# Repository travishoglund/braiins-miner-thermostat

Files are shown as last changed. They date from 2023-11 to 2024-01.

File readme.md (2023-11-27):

# Braiins Miner Thermostat

The purpose of this repo is to help you setup your own Braiins Thermostat for your Miner (S9, S17, S19 supported).

# Features
`Open Source`: Easy to build and assemble if you are a DIY person :)

`Thermostat`: Maintains temperature of your area by enabling or disabling the miner based on the deadband range you set for room temperature.

`Vented`: 3D model is vented so you don't need to run a fan on the unit

## Required Parts:

Approximate Cost: $90

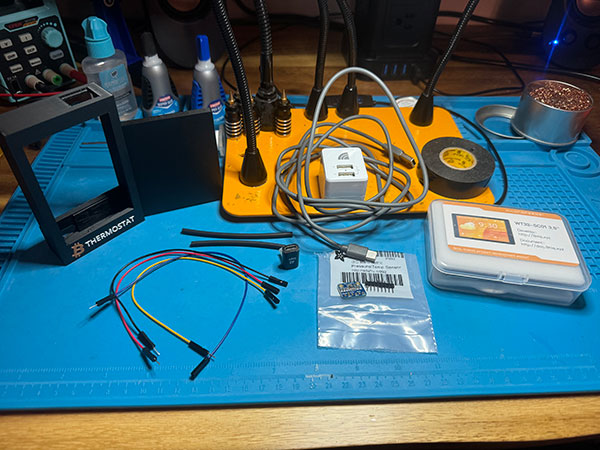
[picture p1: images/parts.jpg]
Parts


- [ESP32 Micro Controller](https://amzn.to/46Gki7e)
- [Temperature Sensor](https://amzn.to/46x0Yt0)
- [90 Degree USBC Adapter](https://amzn.to/3sXdmEE)
- [Shrink Tubing](https://amzn.to/3ojl0H0)
- [Jumper Wires](https://amzn.to/3GPbUIl)
- [90 Degree Jumper Adapter](https://www.amazon.com/dp/B07C89T16T/ref=cm_sw_r_as_gl_api_gl_i_YCH53DA426VD8DCADNQT?linkCode=ml2&tag=wpwtg-20)
- [USBC Power Cable](https://amzn.to/3N3CCjo)
- [Power Adapter](https://amzn.to/49RG3DN)
- You will also need a 3D printer, soldering iron, and an Exacto Knife to clean up the 3D model.

## Assembly Instructions

### Print the 3D Model
Print the models and remove the supports.  The case and door STL's are located in the 3D folder in the repo.<br /><br />
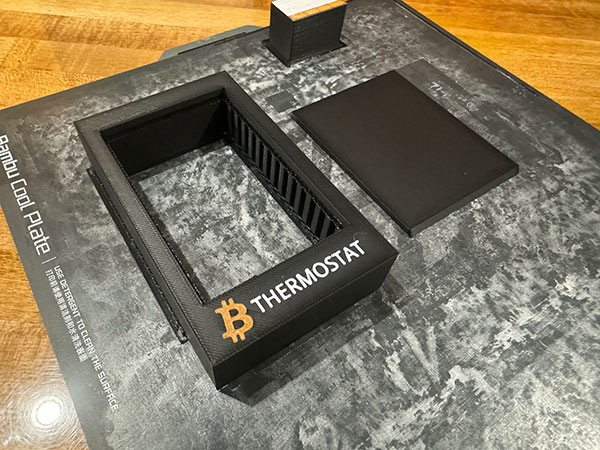
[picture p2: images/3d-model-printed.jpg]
3D Model


### Micro Controller Configuration
While that is printing, lets prepare the micro controller.
- Download the [Arduino IDE](https://www.arduino.cc/en/software)
- Once installed, connect the micro controller to your computer via USBC, and from the dropdown select "Select other board and port...", and select the "ESP32 Dev Module" and on the right select your USB port that it is connected to.
- Copy and paste the code from the arduino-code folder into the editor. Change the variable `thermostatTargetTemp` to your desired room temperature.  (In a future commit this will not be necessary).
- Click the upload button (the second button on the top left).  Once it uploads to the micro controller you should see the Bitcoin ATM screen.  It can safely be removed from the computer and is ready for the assembly into our box.

### Prepare the temperature sensor

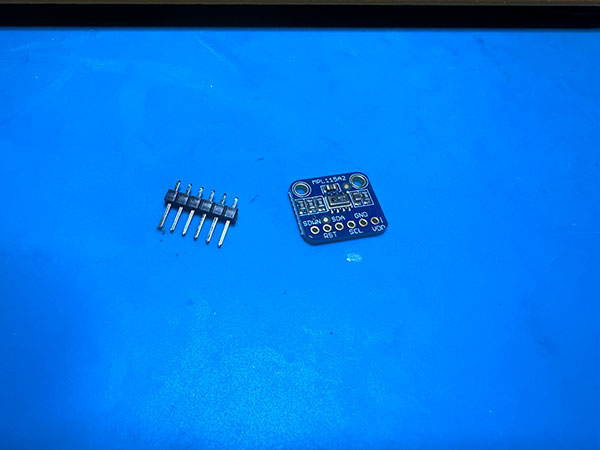
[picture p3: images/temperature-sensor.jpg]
Temperature Sensor
<br />

Solder the pins with the small side up through the board.  I recommend using some flux as the soldering flows much smoother with a small dab of it.  It should look like this:<br /><br />
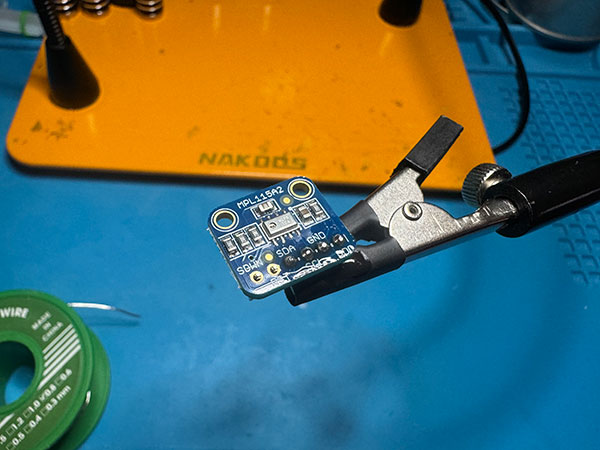
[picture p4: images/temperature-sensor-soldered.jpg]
Temperature Sensor Soldered


### Prepare the jumper wires

Next, we are going to modify the male end of our jumper wires to have a 90 degree bend.<br /><br />
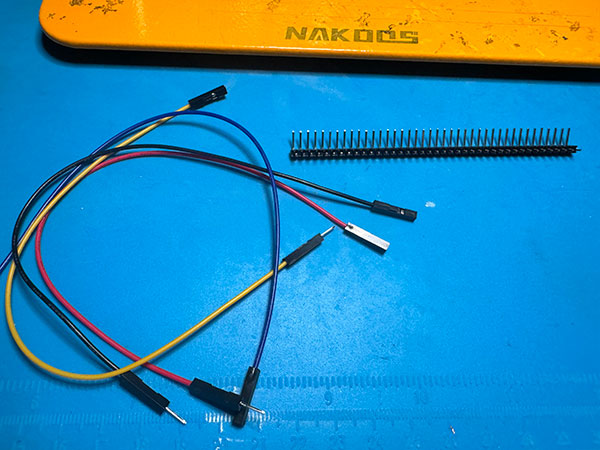
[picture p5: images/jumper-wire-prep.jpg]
Jumper wires


Break apart our 90 degree adapters to individual pieces (qty 4), and solder them to the ends of our jumper wires.<br /><br />
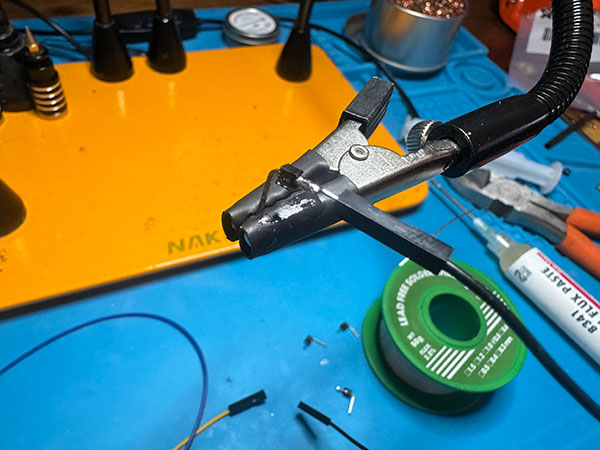
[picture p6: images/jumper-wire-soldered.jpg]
Jumper wires soldered


When soldering is done, cut some shrink tubing (1/8") to about an inch long and heat them around our conversion.<br /><br />
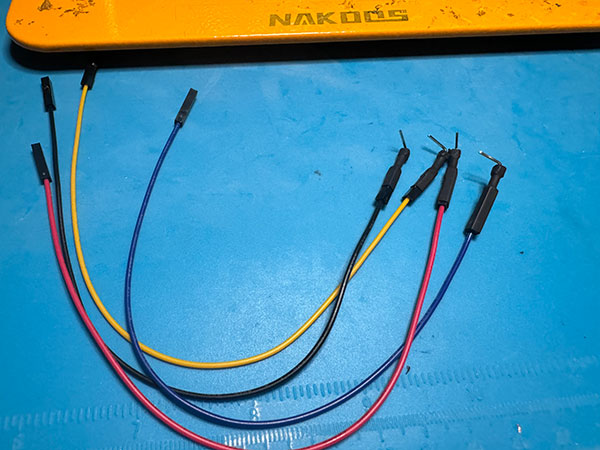
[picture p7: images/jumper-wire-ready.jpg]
Jumper wires complete


### Fitting everything together

Now that everything is ready, we get to assemble everything together.  You will need your 3D model, USBC 90 degree adapter, and Micro Controller display.<br /><br />
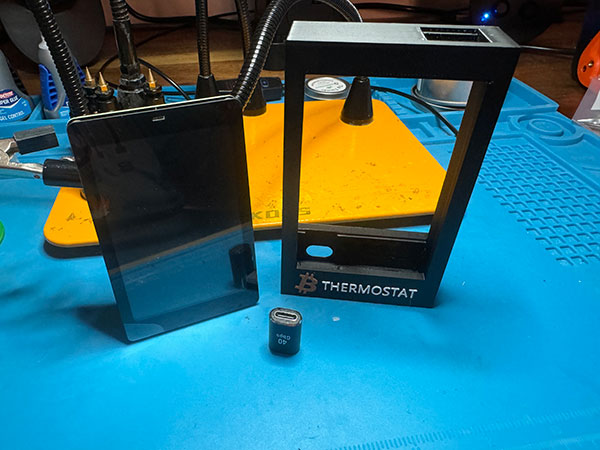
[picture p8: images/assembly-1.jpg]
Assembly 1


Slide the adapter in from the top until you can slide it through the hole in the back of the model.<br /><br />
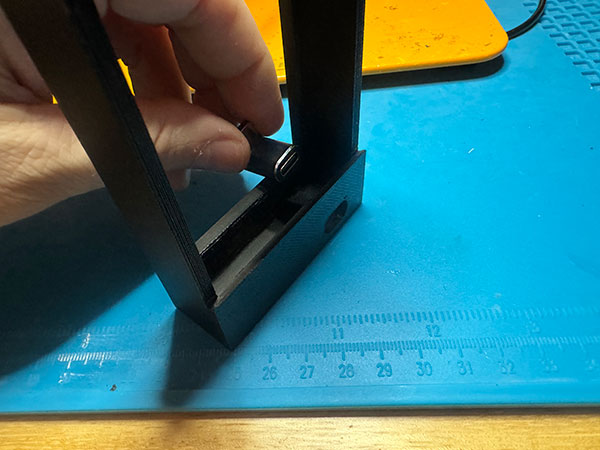
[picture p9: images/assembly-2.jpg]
Assembly 2
<br />
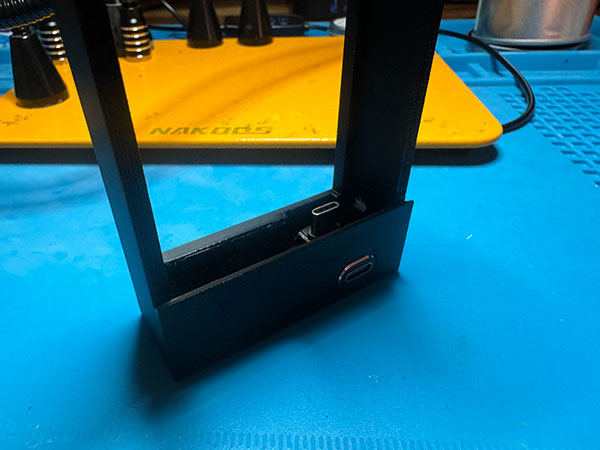
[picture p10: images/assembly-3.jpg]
Assembly 3


Next, take apart the LCD panel. There are tiny little tabs that lock into the metal plate so gently pry them until you can get the top and bottom separated.<br /> <br />
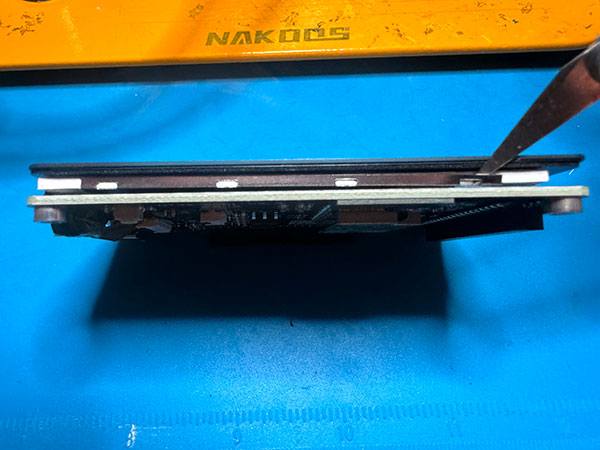
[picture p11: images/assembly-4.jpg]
Assembly 4
<br />
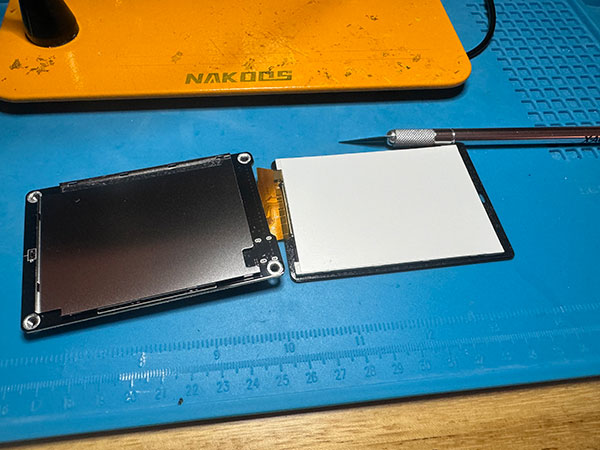
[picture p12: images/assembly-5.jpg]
Assembly 5
<br />

Next, bring the display through the unit at an angle, straighten it out, and line up the usbc port to snap it down into place.<br /><br />
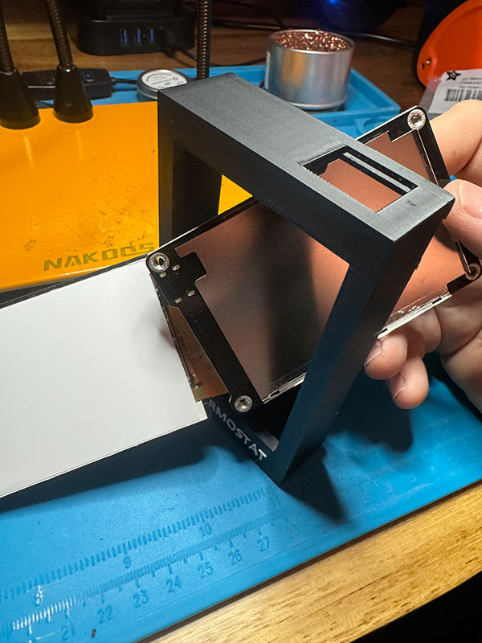
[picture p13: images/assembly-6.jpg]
Assembly 6
<br />
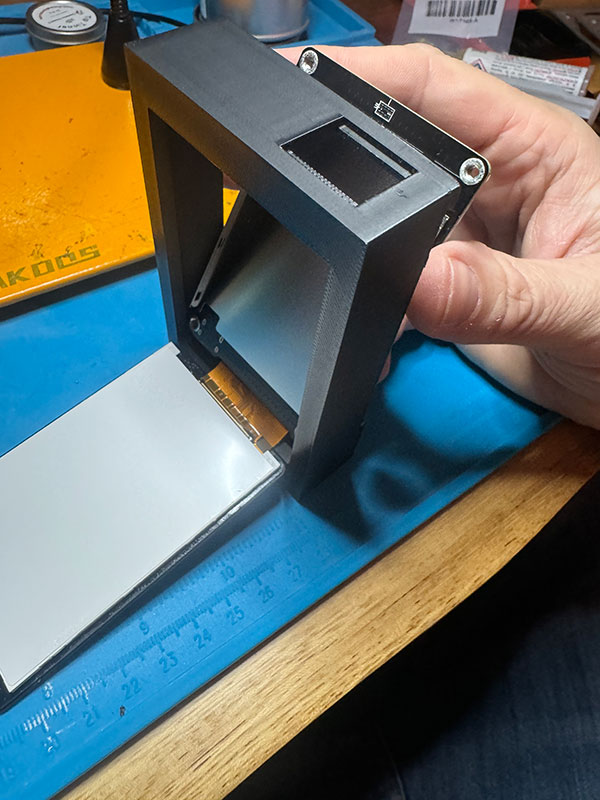
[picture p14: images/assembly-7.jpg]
Assembly 7
<br />
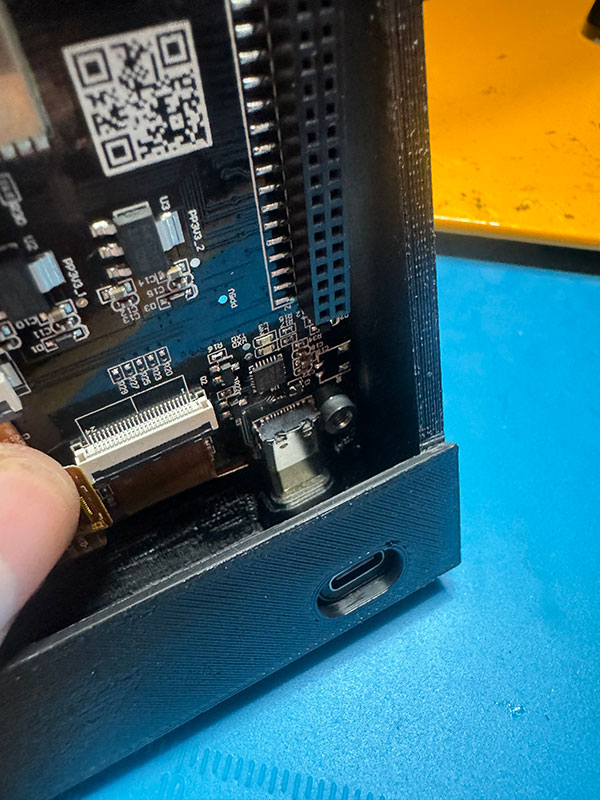
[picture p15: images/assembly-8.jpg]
Assembly 8
<br />

Everything should lock together when you press the display against itself.  I do recommend putting a small amount of hot glue in the top lef/right corners and on the UBBC port inside the model to hold everything even tighter ito place. <br /><br />
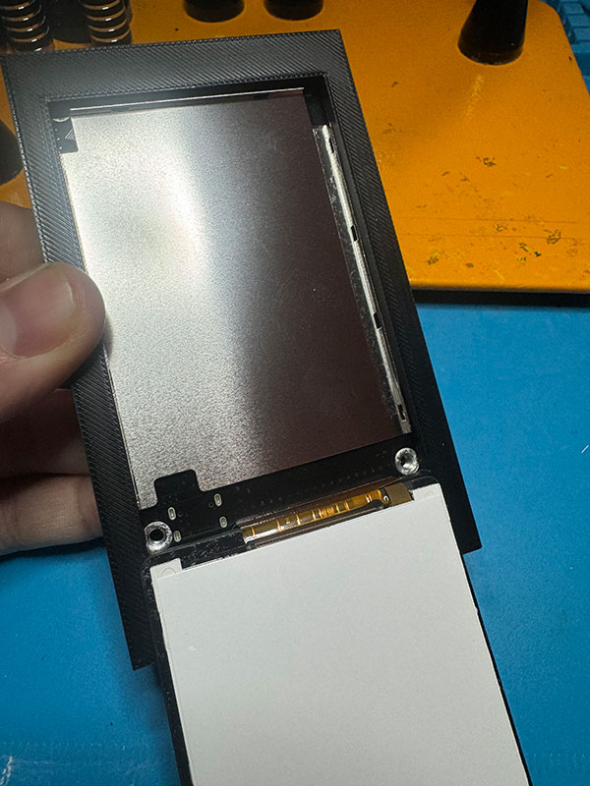
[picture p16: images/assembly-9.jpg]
Assembly 9
<br />
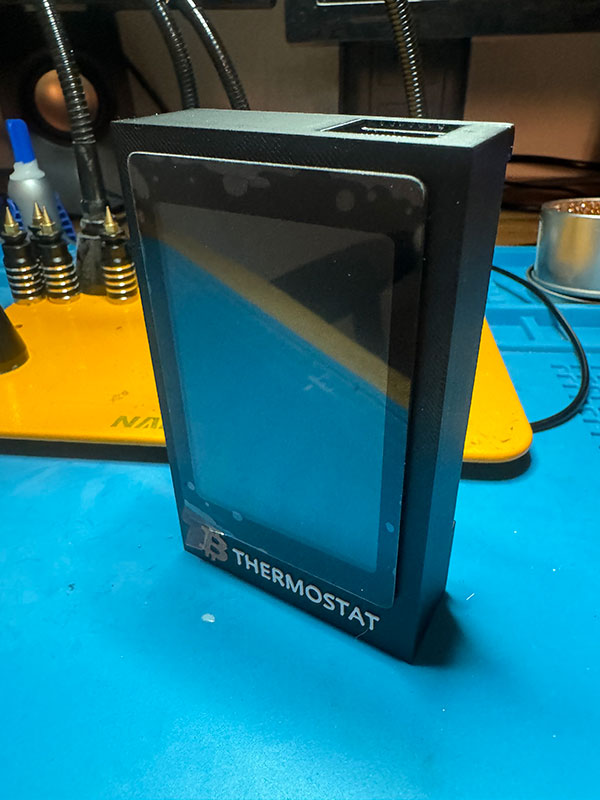
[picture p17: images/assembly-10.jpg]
Assembly 10
<br />

Push the thermostat sensor into the top of the model as shown below<br /><br />
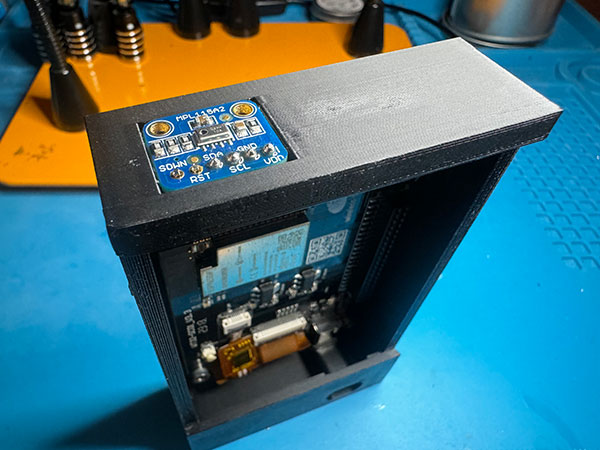
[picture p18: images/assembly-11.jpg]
Assembly 11
<br />

Connect the wires to thermostat sensor and microcontroller as shown:<br /><br />
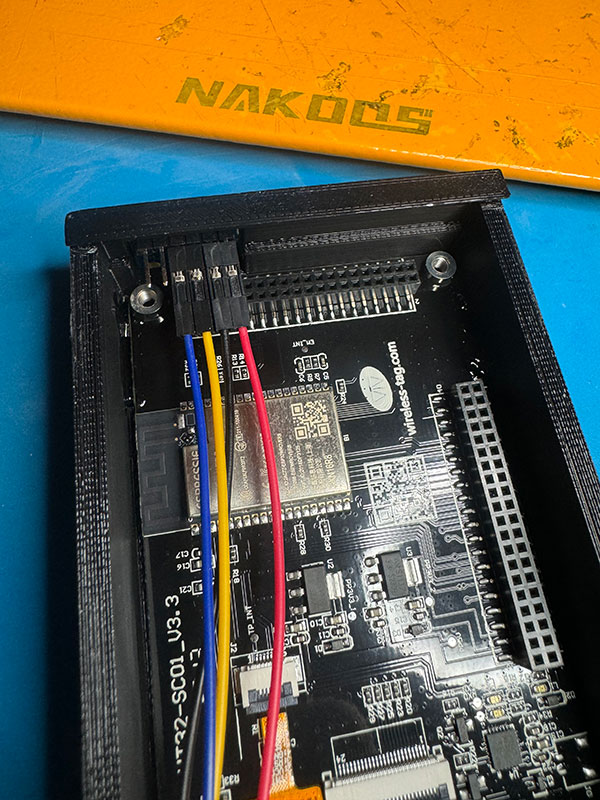
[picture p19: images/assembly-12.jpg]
Assembly 12
<br />

The micro controller pins all go along the back row and are as follows (from the right):
- Red (1)
- Black (3)
- Yellow (8)
- Blue (9)

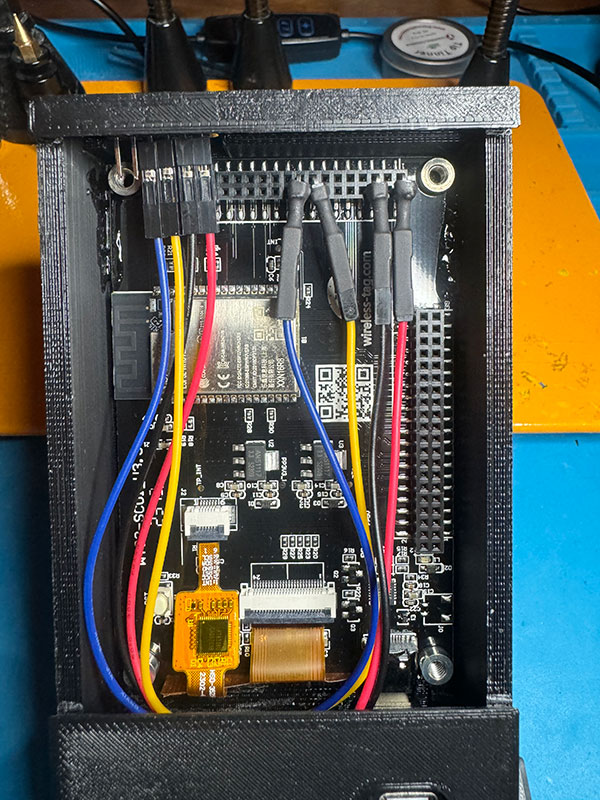
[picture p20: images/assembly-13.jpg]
Assembly 13
<br />

Slide the door on the back and our assembly is ready to run!<br />
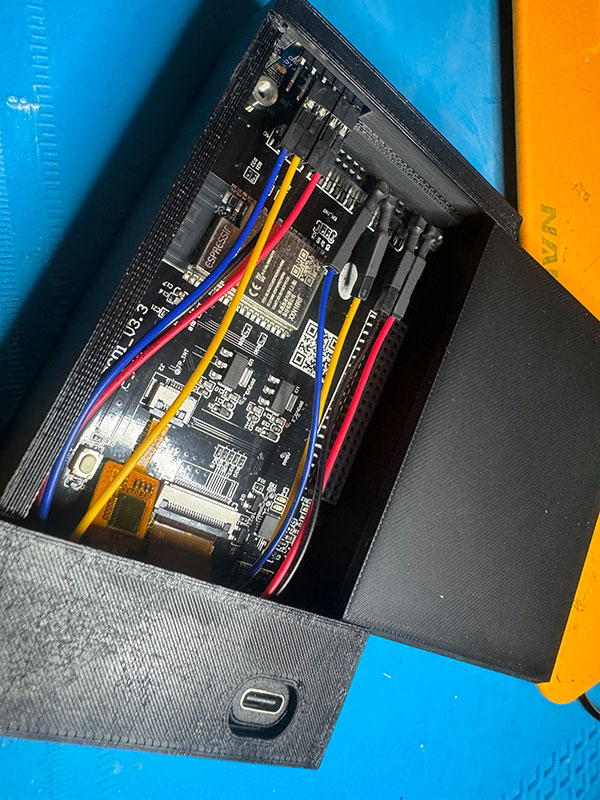
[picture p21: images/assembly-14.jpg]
Assembly 14
<br />
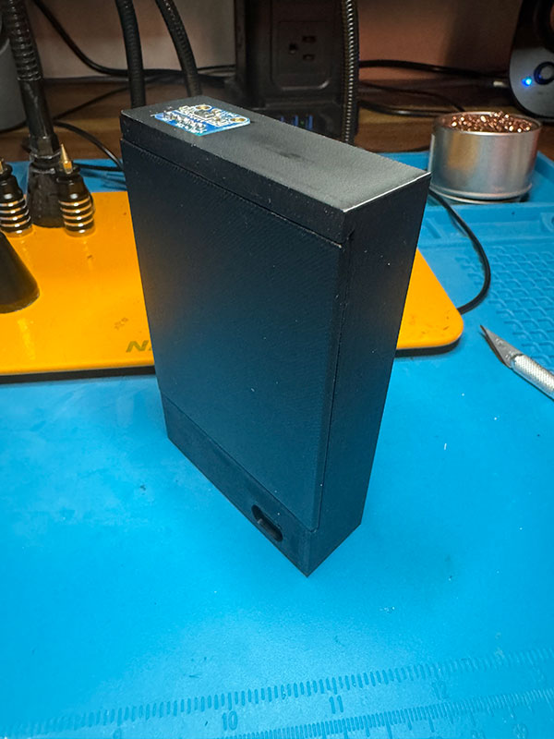
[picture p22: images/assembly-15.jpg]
Assembly 15
<br />
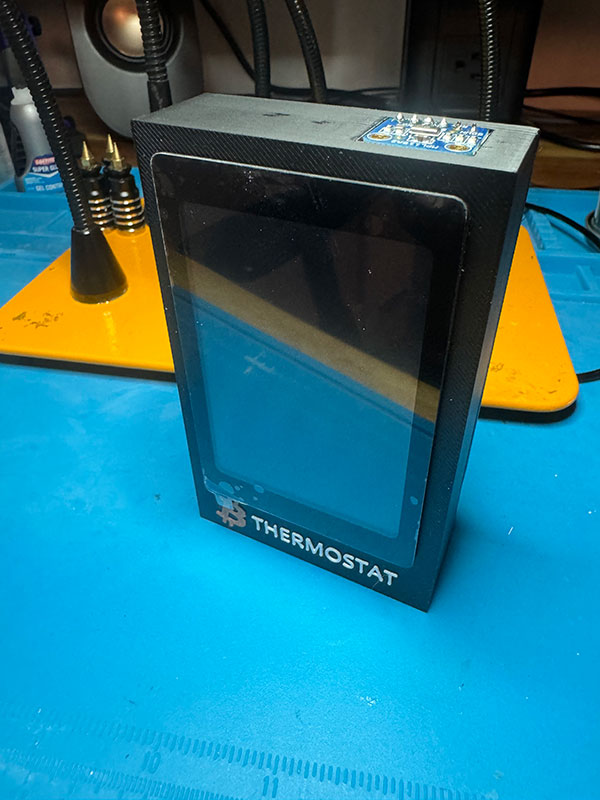
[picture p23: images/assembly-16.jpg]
Assembly 16
<br />

### Final Product
Our final product is ready to use :) <br /><br />

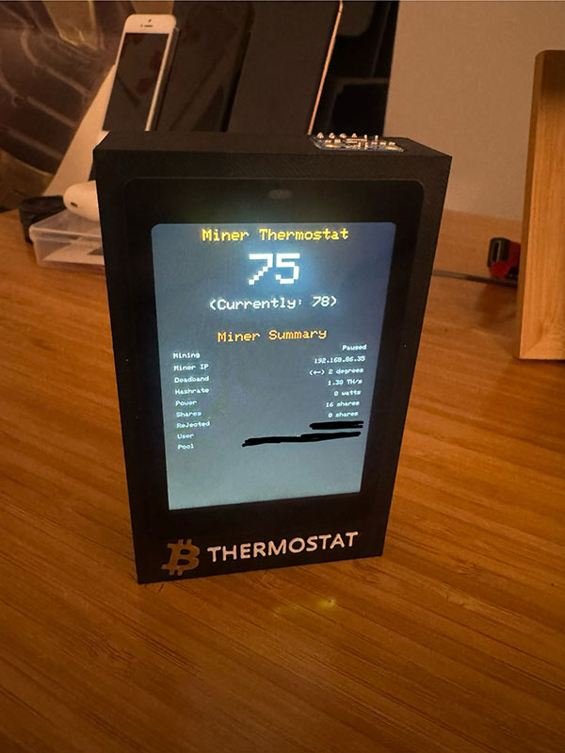
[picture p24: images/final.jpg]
Final
<br />

### Initial Configuration
When the thermostat boots, if it cannot connect to wifi it will enter configuration mode. This mode enables a hotspot that you can connect to on your phone called "BitThermo".  You will not need a password.  Once connected, navigate to http://192.168.4.1 in your browser and enter the configuration settings. When submitted, the device will auto reboot and be all setup!

# License
The code distributed and the product itself is GPLv3.  The purpose of this is to protect the community and ensure that any innovations will remain public under the following license agreements:

1. Anyone can copy, modify and distribute this software.
2. You have to include the license and copyright notice with each and every distribution.
3. You can use this software privately.
4. You can use this software for commercial purposes.
5. If you dare build your business solely from this code, you risk open-sourcing the whole code base.
6. If you modify it, you have to indicate changes made to the code.
7. Any modifications of this code base MUST be distributed with the same license, GPLv3.
8. This software is provided without warranty.
9. The software author or license can not be held liable for any damages inflicted by the software.

More information about this license can be found [here](http://choosealicense.com/licenses/gpl-3.0/).

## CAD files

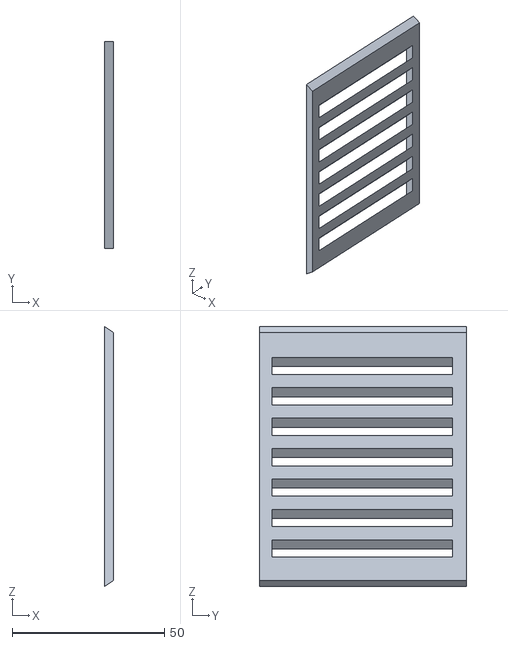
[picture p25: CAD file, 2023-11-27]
3D/DS18B20/thermostat-door-v6.stl
3.01 x 68.0 x 85.5

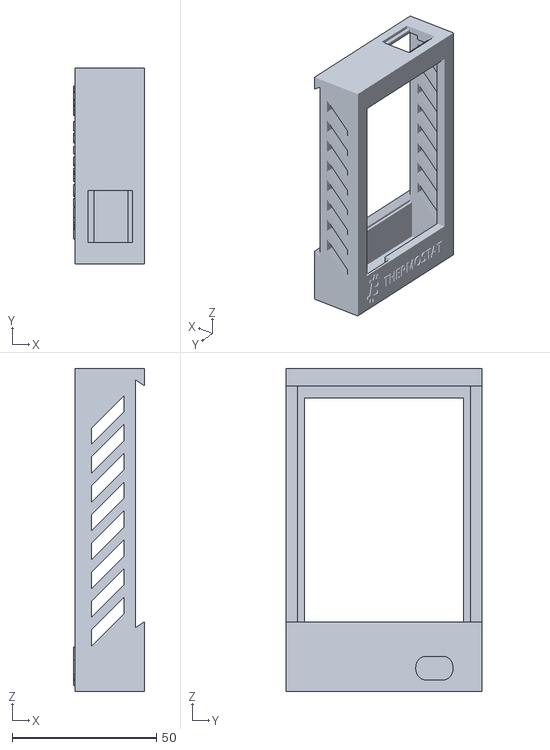
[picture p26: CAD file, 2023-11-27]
3D/standard/thermostat-case-v6.stl
24.5 x 68.0 x 112.0

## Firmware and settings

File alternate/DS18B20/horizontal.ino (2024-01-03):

#include <stdio.h>
#include <freertos/FreeRTOS.h>
#include <freertos/task.h>
#include "sdkconfig.h"
#include <Hash.h>
#include <WiFi.h>
#include <HTTPClient.h>
#include <WiFiUdp.h>
#include <WebServer.h>
#include <EEPROM.h>
#include "qrcoded.h"
#include <ArduinoJson.h>
#include <OneWire.h>
#include <DallasTemperature.h>
// This code is meant for the Horizontal S9 Space Heaters (not multiple miners)

#define SDA 18
#define SCL 19
#define LGFX_WT32_SC01
#define LGFX_USE_V1
#define LGFX_AUTODETECT

#include <LovyanGFX.hpp>

// Program Variables - do not change these
unsigned long lastTemperatureCheckInterrupt;
unsigned long lastMinerUpdateInterrupt;
unsigned long lastNetworkInterrupt;
unsigned long lastTouchInterrupt;
String applicationInfo[12] = {};
boolean wifiFirstPaint = true;
boolean paintScreen = true;
String screen = "init";
String qrData;
boolean firstRun = true;
static int32_t x,y;

// Miner and Thermostat Settings
String minerIPAddressString = "";
IPAddress minerIPAddress;
String minerUser;
String minerPoolAddress;
float minerCurrentHashrateInTh;
int minerCurrentPowerInWatts = 0;
int minerCurrentAcceptedShares = 0;
int minerCurrentRejectedShares = 0;
int thermostatDeadbandRange = 2;
int thermostatTargetTemp = 75;
int thermostatCurrentTemp = 71;
bool minerIsMining = true;
bool debug = false;
bool minerConnected = false;
bool forceConfig = false;


//Network Variables - do not change these
int i = 0;
int statusCode;
const char* ssid = "default_ssid";
const char* passphrase = "default_pass";
String st;
String content;
String esid;
String epass = "";
String edeadband = "3";
String eMinerIp = "";
const int httpsPort = 443;


//Function Decalration
bool testWifi(void);
void launchWeb(void);
void setupAP(void);

// Setting up http for API Calls
WiFiClient client;
HTTPClient http;

//Establishing Local server at port 80
WebServer server(80);

// LCD Display
static LGFX lcd;

// Temperature Sensor
OneWire oneWire(2);
DallasTemperature tempSensor(&oneWire);

const unsigned char bitcoinLogo [] PROGMEM =                                  // 'Bitcoin Logo', 128x64px
{
  0x00, 0x00, 0x00, 0x00, 0x00, 0x00, 0x00, 0x00, 0x00, 0x00, 0x00, 0x00, 0x00, 0x00, 0x00, 0x00,
  0x00, 0x00, 0x00, 0x00, 0x00, 0x00, 0x00, 0x00, 0x00, 0x00, 0x00, 0x00, 0x00, 0x00, 0x00, 0x00,
  0x00, 0x00, 0x00, 0x00, 0x00, 0x00, 0x00, 0x00, 0x00, 0x00, 0x00, 0x00, 0x00, 0x00, 0x00, 0x00,
  0x00, 0x00, 0x00, 0x00, 0x00, 0x00, 0x00, 0x00, 0x00, 0x00, 0x00, 0x00, 0x00, 0x00, 0x00, 0x00,
  0x00, 0x00, 0x00, 0x00, 0x00, 0x00, 0x00, 0xff, 0xf0, 0x00, 0x00, 0x00, 0x00, 0x00, 0x00, 0x00,
  0x00, 0x00, 0x00, 0x00, 0x00, 0x00, 0x07, 0xff, 0xfe, 0x00, 0x00, 0x00, 0x00, 0x00, 0x00, 0x00,
  0x00, 0x00, 0x00, 0x00, 0x00, 0x00, 0x3f, 0xc0, 0x3f, 0xc0, 0x00, 0x00, 0x00, 0x00, 0x00, 0x00,
  0x00, 0x00, 0x00, 0x00, 0x00, 0x00, 0x7c, 0x00, 0x03, 0xe0, 0x00, 0x00, 0x00, 0x00, 0x00, 0x00,
  0x00, 0x00, 0x00, 0x00, 0x00, 0x01, 0xf0, 0x00, 0x00, 0xf8, 0x00, 0x00, 0x00, 0x00, 0x00, 0x00,
  0x00, 0x00, 0x00, 0x00, 0x00, 0x03, 0xc0, 0x00, 0x00, 0x3e, 0x00, 0x00, 0x00, 0x00, 0x00, 0x00,
  0x00, 0x00, 0x00, 0x00, 0x00, 0x0f, 0x00, 0x00, 0x00, 0x0f, 0x00, 0x00, 0x00, 0x00, 0x00, 0x00,
  0x00, 0x00, 0x00, 0x00, 0x00, 0x1e, 0x03, 0xe7, 0xc0, 0x07, 0x80, 0x00, 0x00, 0x00, 0x00, 0x00,
  0x00, 0x00, 0x00, 0x00, 0x00, 0x38, 0x03, 0xe7, 0xc0, 0x01, 0xc0, 0x00, 0x00, 0x00, 0x00, 0x00,
  0x00, 0x00, 0x00, 0x00, 0x00, 0x70, 0x02, 0x24, 0x40, 0x00, 0xe0, 0x00, 0x00, 0x00, 0x00, 0x00,
  0x00, 0x00, 0x00, 0x00, 0x00, 0xe0, 0x02, 0x24, 0x40, 0x00, 0x70, 0x00, 0x00, 0x00, 0x00, 0x00,
  0x00, 0x00, 0x00, 0x00, 0x01, 0xc0, 0x02, 0x24, 0x40, 0x00, 0x38, 0x00, 0x00, 0x00, 0x00, 0x00,
  0x00, 0x00, 0x00, 0x00, 0x01, 0x80, 0x02, 0x24, 0x40, 0x00, 0x1c, 0x00, 0x00, 0x00, 0x00, 0x00,
  0x00, 0x00, 0x00, 0x00, 0x03, 0x80, 0x02, 0x3c, 0x40, 0x00, 0x1c, 0x00, 0x00, 0x00, 0x00, 0x00,
  0x00, 0x00, 0x00, 0x00, 0x07, 0x03, 0xfe, 0x3c, 0x7c, 0x00, 0x0e, 0x00, 0x00, 0x00, 0x00, 0x00,
  0x00, 0x00, 0x00, 0x00, 0x06, 0x03, 0x00, 0x00, 0x1f, 0x00, 0x07, 0x00, 0x00, 0x00, 0x00, 0x00,
  0x00, 0x00, 0x00, 0x00, 0x0e, 0x03, 0x00, 0x00, 0x01, 0xc0, 0x07, 0x00, 0x00, 0x00, 0x00, 0x00,
  0x00, 0x00, 0x00, 0x00, 0x0c, 0x03, 0x00, 0x00, 0x00, 0xc0, 0x03, 0x80, 0x00, 0x00, 0x00, 0x00,
  0x00, 0x00, 0x00, 0x00, 0x1c, 0x03, 0xf0, 0x3f, 0x80, 0x60, 0x03, 0x80, 0x00, 0x00, 0x00, 0x00,
  0x00, 0x00, 0x00, 0x00, 0x18, 0x00, 0xf0, 0x3f, 0xe0, 0x20, 0x01, 0x80, 0x00, 0x00, 0x00, 0x00,
  0x00, 0x00, 0x00, 0x00, 0x38, 0x00, 0x18, 0x30, 0x70, 0x30, 0x01, 0xc0, 0x00, 0x00, 0x00, 0x00,
  0x00, 0x00, 0x00, 0x00, 0x30, 0x00, 0x18, 0x30, 0x10, 0x30, 0x00, 0xc0, 0x00, 0x00, 0x00, 0x00,
  0x00, 0x00, 0x00, 0x00, 0x30, 0x00, 0x18, 0x30, 0x10, 0x30, 0x00, 0xc0, 0x00, 0x00, 0x00, 0x00,
  0x00, 0x00, 0x00, 0x00, 0x70, 0x00, 0x18, 0x30, 0x10, 0x30, 0x00, 0xe0, 0x00, 0x00, 0x00, 0x00,
  0x00, 0x00, 0x00, 0x00, 0x70, 0x00, 0x18, 0x30, 0x30, 0x20, 0x00, 0xe0, 0x00, 0x00, 0x00, 0x00,
  0x00, 0x00, 0x00, 0x00, 0x70, 0x00, 0x18, 0x30, 0xe0, 0x60, 0x00, 0x60, 0x00, 0x00, 0x00, 0x00,
  0x00, 0x00, 0x00, 0x00, 0x60, 0x00, 0x18, 0x3f, 0xc0, 0xc0, 0x00, 0x60, 0x00, 0x00, 0x00, 0x00,
  0x00, 0x00, 0x00, 0x00, 0x60, 0x00, 0x18, 0x00, 0x01, 0xc0, 0x00, 0x60, 0x00, 0x00, 0x00, 0x00,
  0x00, 0x00, 0x00, 0x00, 0x60, 0x00, 0x18, 0x00, 0x00, 0xf0, 0x00, 0x60, 0x00, 0x00, 0x00, 0x00,
  0x00, 0x00, 0x00, 0x00, 0x60, 0x00, 0x18, 0x00, 0x00, 0x38, 0x00, 0x60, 0x00, 0x00, 0x00, 0x00,
  0x00, 0x00, 0x00, 0x00, 0x60, 0x00, 0x18, 0x3f, 0xe0, 0x18, 0x00, 0x60, 0x00, 0x00, 0x00, 0x00,
  0x00, 0x00, 0x00, 0x00, 0x60, 0x00, 0x18, 0x30, 0xf8, 0x0c, 0x00, 0x60, 0x00, 0x00, 0x00, 0x00,
  0x00, 0x00, 0x00, 0x00, 0x70, 0x00, 0x18, 0x30, 0x1c, 0x0c, 0x00, 0x60, 0x00, 0x00, 0x00, 0x00,
  0x00, 0x00, 0x00, 0x00, 0x70, 0x00, 0x18, 0x30, 0x0c, 0x0c, 0x00, 0xe0, 0x00, 0x00, 0x00, 0x00,
  0x00, 0x00, 0x00, 0x00, 0x70, 0x00, 0x18, 0x30, 0x04, 0x0c, 0x00, 0xe0, 0x00, 0x00, 0x00, 0x00,
  0x00, 0x00, 0x00, 0x00, 0x30, 0x00, 0x18, 0x30, 0x0c, 0x0c, 0x00, 0xc0, 0x00, 0x00, 0x00, 0x00,
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
};

/**
 * Helper Functions
 */
 void charBounds(char c, int16_t *x, int16_t *y,
	int16_t *minx, int16_t *miny, int16_t *maxx, int16_t *maxy) {

	if (!true) {}
	else { // Default font

		if (c == '\n') {                     // Newline?
			*x = 0;                        // Reset x to zero,
			*y += lcd.getTextSizeX() * 8;             // advance y one line
			// min/max x/y unchaged -- that waits for next 'normal' character
		}
		else if (c != '\r') {  // Normal char; ignore carriage returns
			if (/*wrap*/ false && ((*x + lcd.getTextSizeX() * 6) > lcd.width())) { // Off right?
				*x = 0;                    // Reset x to zero,
				*y += lcd.getTextSizeX() * 8;         // advance y one line
			}
			int x2 = *x + lcd.getTextSizeX() * 6 - 1, // Lower-right pixel of char
				y2 = *y + lcd.getTextSizeX() * 8 - 1;
			if (x2 > *maxx) *maxx = x2;      // Track max x, y
			if (y2 > *maxy) *maxy = y2;
			if (*x < *minx) *minx = *x;      // Track min x, y
			if (*y < *miny) *miny = *y;
			*x += lcd.getTextSizeX() * 6;             // Advance x one char
		}
	}
}

void getTextBounds(const char *str, int16_t x, int16_t y,
	int16_t *x1, int16_t *y1, uint16_t *w, uint16_t *h) {
	uint8_t c; // Current character

	*x1 = x;
	*y1 = y;
	*w = *h = 0;

	int16_t minx = lcd.width(), miny = lcd.width(), maxx = -1, maxy = -1;

	while ((c = *str++))
		charBounds(c, &x, &y, &minx, &miny, &maxx, &maxy);

	if (maxx >= minx) {
		*x1 = minx;
		*w = maxx - minx + 1;
	}
	if (maxy >= miny) {
		*y1 = miny;
		*h = maxy - miny + 1;
	}
}

// Prints centered text
void printLeft(const String buf, int x, int y, long color = TFT_WHITE)                          //Function to centre the current price in the display width
{
  int16_t x1, y1;
  lcd.setTextColor(color, TFT_BLACK);
  lcd.setCursor(x, y);                          //Set cursor to print string in centre
  lcd.print(buf);                                                     //Display string
}

void printCenter(const String buf, int x, int y, long color = TFT_WHITE)                          //Function to centre the current price in the display width
{
  int16_t x1, y1;
  uint16_t w, h;
  getTextBounds(buf.c_str(), x, y, &x1, &y1, &w, &h);                     //Calculate string width
  lcd.setTextColor(color, TFT_BLACK);
  lcd.setCursor((x - w / 2) + (480 / 2), y);                          //Set cursor to print string in centre
  lcd.print(buf);                                                     //Display string
}

void printRight(const String buf, int x, int y, long color = TFT_WHITE)                          //Function to centre the current price in the display width
{
  int16_t x1, y1;
  uint16_t w, h;
  getTextBounds(buf.c_str(), x, y, &x1, &y1, &w, &h);                     //Calculate string width
  lcd.setTextColor(color, TFT_BLACK);
  lcd.setCursor(480 + x - w, y);                          //Set cursor to print string in centre
  lcd.print(buf);                                                     //Display string
}

/**
 * Application Functions
 */
 // Adds application info the to stack to be used easily within the application
void addApplicationInfo(String info){
  if(debug) Serial.println(info);
  for (int i = 0; i < 12; i++) {
    if (applicationInfo[i] == NULL) {
      applicationInfo[i] = info;
      return;
    }
  }
}

void resetToHomeScreen() {
  clearApplicationInfo();
  screen = "home";
  lastTemperatureCheckInterrupt = millis();
}

void showQrCode(String qrData, int xOffset, int yOffset) {
  const char *qrDataChar = qrData.c_str();
  QRCode qrcoded;
  uint8_t qrcodeData[qrcode_getBufferSize(20)];
  qrcode_initText(&qrcoded, qrcodeData, 6, 0, qrDataChar);

  for (uint8_t y = 0; y < qrcoded.size; y++)
  {
    for (uint8_t x = 0; x < qrcoded.size; x++)
    {
      if (qrcode_getModule(&qrcoded, x, y))
      {
        lcd.fillRect(xOffset + 4 * x, yOffset + 4 * y, 4, 4, TFT_ORANGE);
      }
      else
      {
        lcd.fillRect(xOffset + 4 * x, yOffset + 4 * y, 4, 4, TFT_BLACK);
      }
    }
  }
}

// Clears application stack messages
void clearApplicationInfo() {
  memset(applicationInfo, '\0', sizeof(applicationInfo));
}

/**
 * Miner Connection
 */
String sendMinerCommand(String command) {

  if(debug) ("Connecting to Miner");
  minerIPAddress.fromString(minerIPAddressString);
  if (client.connect(minerIPAddress, (uint16_t)4028, int32_t(1000))) {                 // Establish a connection

      if (client.connected()) {
        client.println("{\"command\": \""+command+"\"}");
      }

      while (!client.available());                // wait for response

      String response = client.readStringUntil('\n');  // read entire response
      if(debug) Serial.print("[Rx] ");
      if(debug) Serial.println(response);

      return response;

  }

  return "";

}

/*
 * Halt Mining - the room is too warm
 */
void stopMinerMining() {
  minerIsMining = false;
  sendMinerCommand("pause");
}

/*
 * Resume Mining - the room is too cool
 */
void startMinerMining() {
  minerIsMining = true;
  sendMinerCommand("resume");
}

/*
 * Checks the room temperature and pauses/starts mining
 */
void checkRoomTemperature() {

  lastTemperatureCheckInterrupt = millis();

  // Refresh Temperature
  tempSensor.requestTemperatures();
  float tempCelsius = tempSensor.getTempCByIndex(0);
  float tempFahrenheit = tempCelsius * 9 / 5 + 32;

  if(debug) Serial.println(tempFahrenheit);
  if(tempFahrenheit > 0) {
    if( tempFahrenheit <= (thermostatTargetTemp - thermostatDeadbandRange) ) {
    startMinerMining();
    } else if(tempFahrenheit >= (thermostatTargetTemp + thermostatDeadbandRange) ) {
      stopMinerMining();
    }

    int currentTemperatureReading = (int)(tempFahrenheit + 0.5);
    if(currentTemperatureReading > 0 && currentTemperatureReading != thermostatCurrentTemp && screen != "init") {
      thermostatCurrentTemp = currentTemperatureReading;
      lcd.setTextSize(2);
      printLeft(" (Now: " + (String)thermostatCurrentTemp + ") ", 15, 100, TFT_WHITE);
    }
  }

}

/**
 * Gets the latest info from the miner
 */
void updateMinerData(){

  lastMinerUpdateInterrupt = millis();

  String summaryResponse = sendMinerCommand("summary");
  String tunerResponse = sendMinerCommand("tunerstatus");
  String poolsResponse = sendMinerCommand("pools");
  StaticJsonDocument<2000> doc;

  DeserializationError error = deserializeJson(doc, summaryResponse);
  if (!error) {
    minerConnected = true;
    minerCurrentHashrateInTh = doc["SUMMARY"][0]["MHS 5s"].as<float>() / 1000000;
    minerCurrentAcceptedShares = doc["SUMMARY"][0]["Accepted"].as<int>();
    minerCurrentRejectedShares = doc["SUMMARY"][0]["Rejected"].as<int>();
  }

  error = deserializeJson(doc, tunerResponse);
  if (!error) {
    minerCurrentPowerInWatts = doc["TUNERSTATUS"][0]["ApproximateMinerPowerConsumption"].as<int>();
  }

  error = deserializeJson(doc, poolsResponse);
  if (!error) {
    minerUser = doc["POOLS"][0]["User"].as<String>();
    minerPoolAddress = doc["POOLS"][0]["Stratum URL"].as<String>();
  }

  paintScreen = true;

}

/**
 * Screens for Application
 */
void infoScreen()
{
  int cursorX = 20;
  int cursorY = 0;
  lcd.fillScreen(TFT_BLACK);
  lcd.setTextColor(TFT_WHITE, TFT_BLACK);
  lcd.setTextSize(2);
  for (int i = 0; i < 12; i++) {
    if (applicationInfo[i]) {
      cursorY = cursorY + 30;
      lcd.setCursor(cursorX, cursorY);
      lcd.println(applicationInfo[i]);
      delay(500);
    }
  }
}

void homeScreen(){

  clearApplicationInfo();
  int startSummaryAtY = 12;

  lcd.fillScreen(TFT_BLACK);
  lcd.setTextColor(TFT_ORANGE, TFT_BLACK);
  lcd.setTextSize(2);

  // Thermostat Settings
  printLeft("Thermostat", 30, 12, TFT_ORANGE);
  lcd.setTextColor(TFT_WHITE, TFT_BLACK);
  lcd.setTextSize(4);
  printLeft((String)thermostatTargetTemp, 65, 46, TFT_WHITE);
  printLeft("-", 25, 46, TFT_WHITE);
  printLeft("+", 125, 46, TFT_WHITE);
  lcd.setTextSize(2);
  printLeft(" (Now: " + (String)thermostatCurrentTemp + ") ", 20, 100, TFT_WHITE);
  lcd.setTextColor(TFT_ORANGE, TFT_BLACK);
  lcd.setTextSize(2);

  // Miner Summary
  printLeft("Summary", 300, startSummaryAtY, TFT_ORANGE);
  lcd.setTextColor(TFT_WHITE, TFT_BLACK);
  lcd.setTextSize(1);
  // Row 1 - Mining
  printLeft("Mining", 210, startSummaryAtY + 30, TFT_WHITE);
  printRight(minerIsMining ? "Active" : "Paused", -20, startSummaryAtY + 30, TFT_WHITE);
  // Row 1 - IP
  printLeft("Miner IP", 210, startSummaryAtY + 50, TFT_WHITE);
  printRight((String)minerIPAddressString, -20, startSummaryAtY + 50, TFT_WHITE);
  // Row 2 - Deadband
  printLeft("Deadband", 210, startSummaryAtY + 70, TFT_WHITE);
  printRight("(+-) " + (String)thermostatDeadbandRange + " degrees", -20, startSummaryAtY + 70, TFT_WHITE);
  // Row 3 - Hashrate
  printLeft("Hashrate", 210, startSummaryAtY + 90, TFT_WHITE);
  printRight((String)minerCurrentHashrateInTh + " TH/s", -20, startSummaryAtY + 90, TFT_WHITE);
  // Row 4 - Power
  printLeft("Power", 210, startSummaryAtY + 110, TFT_WHITE);
  printRight((String)minerCurrentPowerInWatts + " watts", -20, startSummaryAtY + 110, TFT_WHITE);
  // Row 5 - Shares
  printLeft("Shares", 210, startSummaryAtY + 130, TFT_WHITE);
  printRight(String(minerCurrentAcceptedShares) + " shares", -20, startSummaryAtY + 130, TFT_WHITE);
  // Row 6 - Rejected Shares
  printLeft("Rejected", 210, startSummaryAtY + 150, TFT_WHITE);
  printRight(String(minerCurrentRejectedShares) + " shares", -20, startSummaryAtY + 150, TFT_WHITE);
  // Row 7 - User
  printLeft("User", 210, startSummaryAtY + 170, TFT_WHITE);
  printRight((String)minerUser, -20, startSummaryAtY + 170, TFT_WHITE);
  // Row 7 - Pool
  printLeft("Pool", 210, startSummaryAtY + 190, TFT_WHITE);
  printRight((String)minerPoolAddress, -20, startSummaryAtY + 190, TFT_WHITE);

  // Miner Connection & Reset Button
  lcd.drawCircle(460, 300, 10, (minerConnected == true ? TFT_GREEN : TFT_RED));
  lcd.setTextColor(TFT_WHITE, TFT_BLACK);
  lcd.setTextSize(1);
  lcd.setCursor(20, 300);
  lcd.print("Reset");

}


/**
 * Network Functions for testing connectability
 */
bool testWifi(void) {
  int c = 0;
  while ( c < 20 ) {
    if (WiFi.status() == WL_CONNECTED)
    {
      return true;
    }
    delay(500);
    if(debug) Serial.print("*");
    c++;
  }
  if(debug) Serial.println("");
  if(debug) Serial.println("Connect timed out, opening AP");
  return false;
}

void launchWeb() {
  if(debug) Serial.println("");
  if (WiFi.status() == WL_CONNECTED) {
    Serial.println("WiFi connected");
    Serial.print("Local IP: ");
    Serial.println(WiFi.localIP());
    Serial.print("SoftAP IP: ");
    Serial.println(WiFi.softAPIP());
  }
  createWebServer();
  // Start the server
  server.begin();
  if(debug) Serial.println("Server started");
}

void setupAP(void) {
  WiFi.mode(WIFI_STA);
  WiFi.disconnect();
  delay(100);
  int n = WiFi.scanNetworks();
  if(debug) Serial.println("scan done");
  if (n == 0)
    if(debug) Serial.println("no networks found");
  else
  {
    if(debug) Serial.print(n);
    if(debug) Serial.println(" networks found");
    for (int i = 0; i < n; ++i)
    {
      if(debug) {
        Serial.print(i + 1);
        Serial.print(": ");
        Serial.print(WiFi.SSID(i));
        Serial.print(" (");
        Serial.print(WiFi.RSSI(i));
        Serial.print(")");
      }
      //Serial.println((WiFi.encryptionType(i) == ENC_TYPE_NONE) ? " " : "*");
      delay(10);
    }
  }
  if(debug) Serial.println("");
  st = "<ol>";
  for (int i = 0; i < n; ++i)
  {
    // Print SSID and RSSI for each network found
    st += "<li>";
    st += WiFi.SSID(i);
    st += " (";
    st += WiFi.RSSI(i);

    st += ")";
    //st += (WiFi.encryptionType(i) == ENC_TYPE_NONE) ? " " : "*";
    st += "</li>";
  }
  st += "</ol>";
  delay(100);
  WiFi.softAP("BitThermo", "");
  if(debug) Serial.println("Initializing_softap_for_wifi credentials_modification");
  launchWeb();
  if(debug) Serial.println("over");
  lcd.setCursor(40, 280);
}
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
void loop() {

  // Wifi is connected properly
  if (forceConfig == false && (WiFi.status() == WL_CONNECTED))
  {
    // Refresh temperature status every 5 seconds
    if(screen != "init" && (millis() - lastTemperatureCheckInterrupt > 3000)) {
      checkRoomTemperature();
    }

    if(screen != "init" && (millis() - lastMinerUpdateInterrupt > 30000)) {
      updateMinerData();
    }

    // Screen Logic
    if(paintScreen) {
      paintScreen = false;
      if(screen == "init") {
        addApplicationInfo("Connected to:");
        addApplicationInfo(esid);
        infoScreen();
        checkRoomTemperature();
        updateMinerData();
        delay(5000);
        screen = "home";
        paintScreen = true;
      } else if(screen == "home") {
        homeScreen();
      } else {
        infoScreen();
      }
    }

    // Temperature Adjustment
    if (lcd.getTouch(&x, &y)) {
        // Adjust temp down
        if(x > 0 && x < 75 && y > 45 && y < 95) {
          if(millis() - lastTouchInterrupt > 500) {
            lastTouchInterrupt = millis();
            thermostatTargetTemp--;
            lcd.setTextColor(TFT_WHITE, TFT_BLACK);
            lcd.setTextSize(4);
            printLeft((String)thermostatTargetTemp, 65, 46, TFT_WHITE);
          }
        }
        // Adjust temp up
        if(x > 105 && x < 180 && y > 45 && y < 95) {
          if(millis() - lastTouchInterrupt > 500) {
            lastTouchInterrupt = millis();
            thermostatTargetTemp++;
            lcd.setTextColor(TFT_WHITE, TFT_BLACK);
            lcd.setTextSize(4);
            printLeft((String)thermostatTargetTemp, 65, 46, TFT_WHITE);
          }
        }
        // Enter Config Mode
        if(x >= 0 && x <= 90 && y >= 300 && y <= 320) {
          EEPROM.write(97, 1);
          EEPROM.commit();
          ESP.restart();
        }
      }
  }

  // Setup Access Point due to no internet connection
  if(firstRun) {
    if (forceConfig == false && testWifi() && (digitalRead(15) != 1))
    {} else {
      // Setup HotSpot and show user that Connection is ready
      firstRun = false;
      clearApplicationInfo();
      addApplicationInfo("No Wifi, Hotspot on");
      addApplicationInfo("Connect to BitThermo");
      addApplicationInfo("Set wifi ssid at:");
      addApplicationInfo("192.168.4.1");
      infoScreen();
      showQrCode("http://192.168.4.1", 295, 125);
      launchWeb();
      setupAP();// Setup HotSpot
    }
  }

  // Waiting for connection details through Access Point
  if ((WiFi.status() != WL_CONNECTED))
  {
    if((millis() - lastNetworkInterrupt > 5000)) {
      lastNetworkInterrupt = millis();
      Serial.print(".");
      server.handleClient();
    }
  }
}

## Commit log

2023-11-27 Open source ready
    [thermostat-case-v6.stl, thermostat-door-v6.stl]
2024-01-03 Added multiple miner support and reset button
    [thermostat-case-v6.stl, thermostat-door-v6.stl]
2024-01-03 Updated horizontal layout for S9 space heater
